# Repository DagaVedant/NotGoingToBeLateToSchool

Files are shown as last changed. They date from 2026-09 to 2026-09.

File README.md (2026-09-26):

# NotGoingToBeLateToSchool

a 9 key alarm clock that makes you type a code to shut it up.

built on a xiao esp32c3 for BLARE. during the day it sits on my desk cycling through
weather, hackatime hours, now playing and world clocks. at 6am it tells my phone to start
playing spotify instead of screaming at me with a piezo. you get 3 snoozes, and on the 3rd
one you have to type a code on the keypad before it stops.

every alarm clock i've had is useless for the 16 hours a day you're awake, and way too easy
to snooze into oblivion. this one tries to fix both.

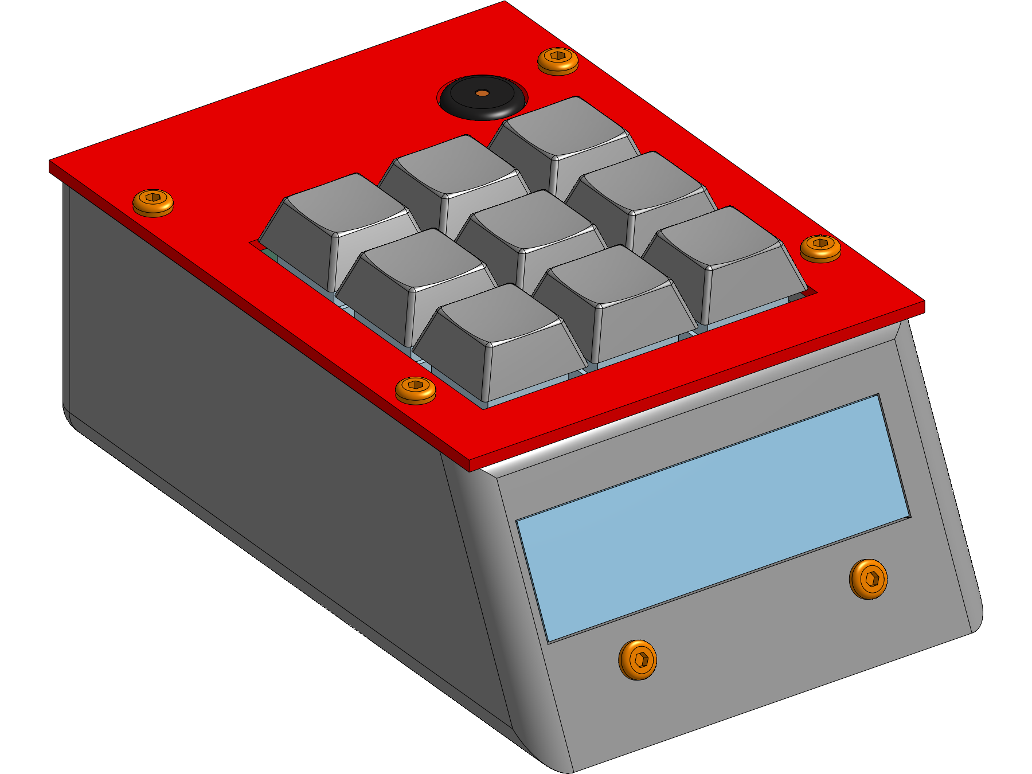
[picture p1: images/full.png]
notgoingtobelatetoschool


the top plate and the pcb share hardware: one m3x16 screw per corner runs down through the
top plate boss and the board into the same heatset insert the pcb post already carries, so
there's no separate top-plate insert or screw anymore. simpler, but the board can't come out
without pulling the top plate first. the bosses sit over the board, so they need a bit of
support when printing the base.

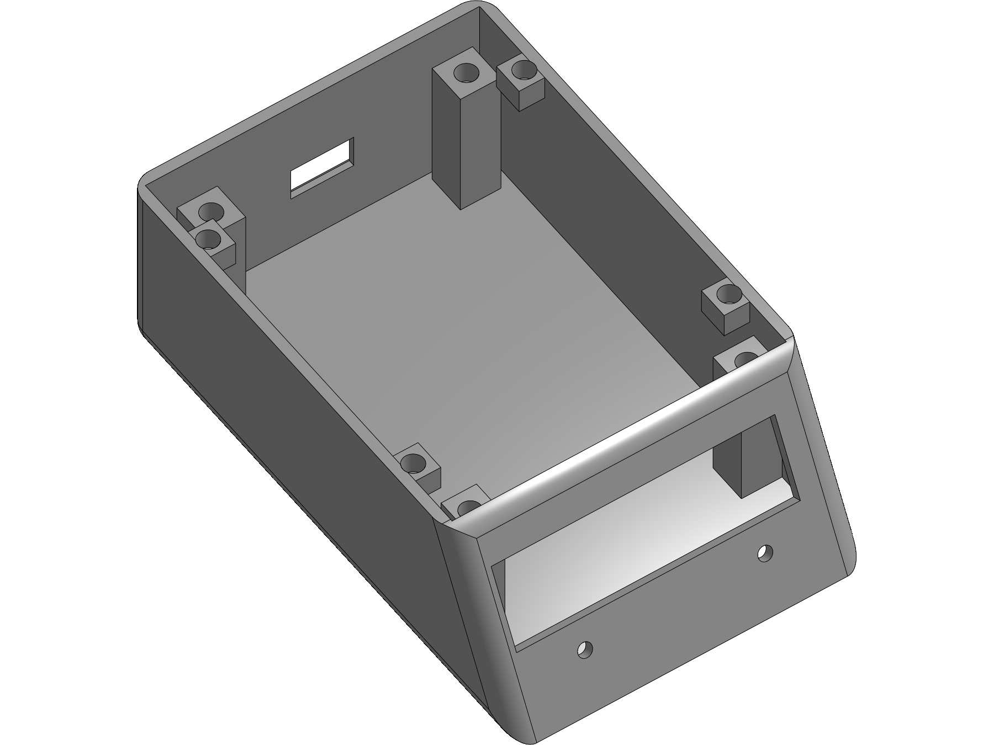
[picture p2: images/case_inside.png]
inside the case


the pcb sits on four posts that land exactly on its mounting holes. the xiao is socketed on
the underside, so its usb-c port ends up 13mm below the board, and the slot in the back wall
is cut around that spot, not at board height.

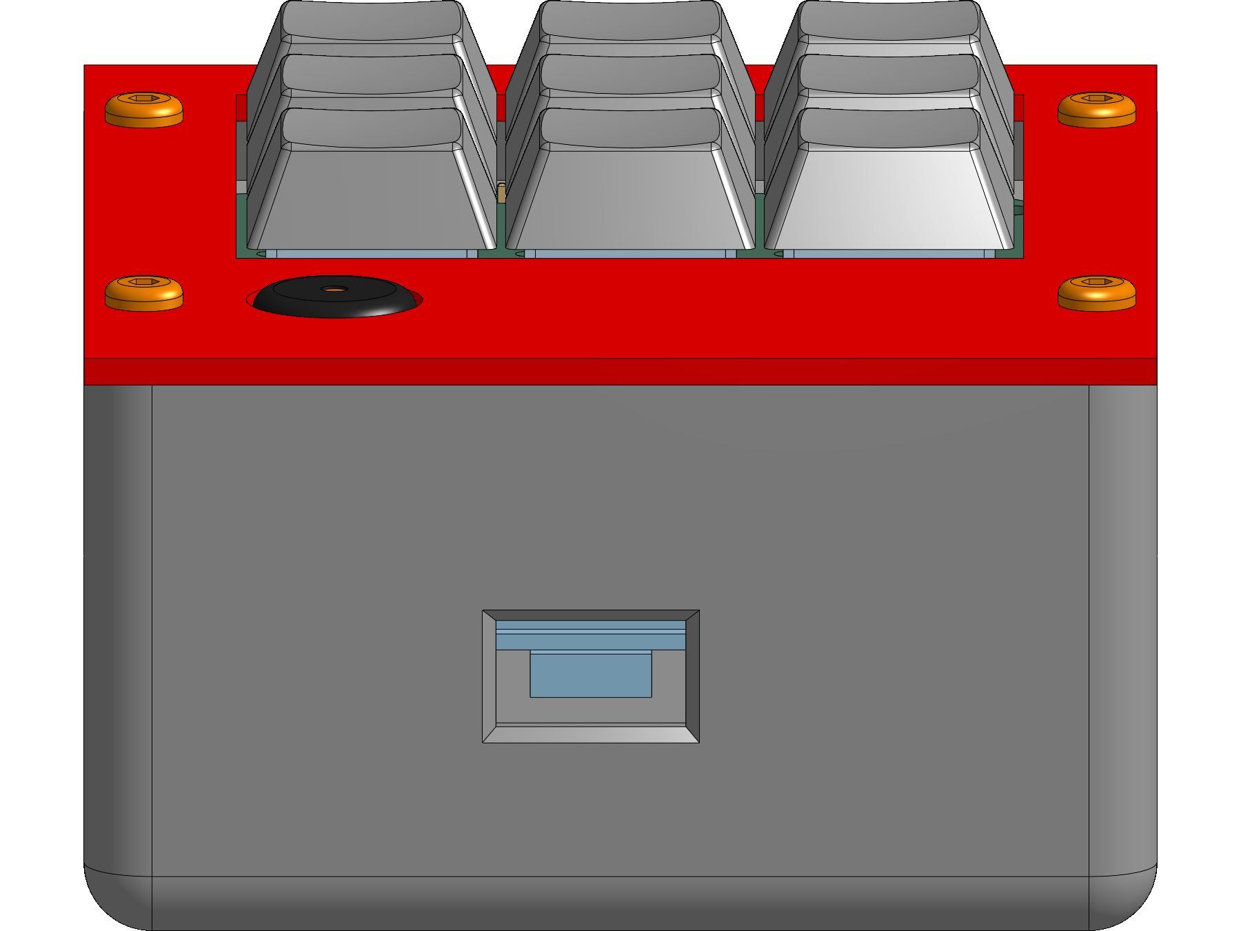
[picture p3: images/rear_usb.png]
rear usb slot


## what it does

**ambient**, all day

- auto rotates through weather / hackatime hours / now playing / world clocks
- spinning globe on the clock face, same animation as the oled on my hackpad
- one small json from a relay covers all four pages, so the clock makes one https request
  a minute instead of juggling four apis itself

**alarm**, at 6am

- multiple alarms, each with its own days of the week, all editable on the device
- 3 snoozes max. the first two are normal, on the 3rd it drops into code entry and keeps
  going until you type the right code
- screen fades up from near black to full brightness over the 15 min before the alarm
- escalating piezo buzzer that speeds up the longer you ignore it

**ble**, written and compiling, never run on hardware

- pairs as a ble media remote so the alarm hits play on my phone instead of buzzing
- iphone notifications over ancs

## the board

69.5 x 97mm, 2 layers, 25 footprints. 461 tracks, 14 vias, about 1.5m of copper. drc clean,
nothing unrouted.

- keys on the top side at 19.05 pitch so the caps clear each other
- xiao and display header on the underside, so the top face is just keycaps and the buzzer
- xiao at the back with usb-c out the rear, on 2.54 sockets so it can be pulled out
- 8 pin display header at the front edge so the jumper run to the screen is short
- one diode per switch, sitting in the 3.45mm gap directly below it
- 4x m3 mounting holes, pushed out to the corners so they clear the key block

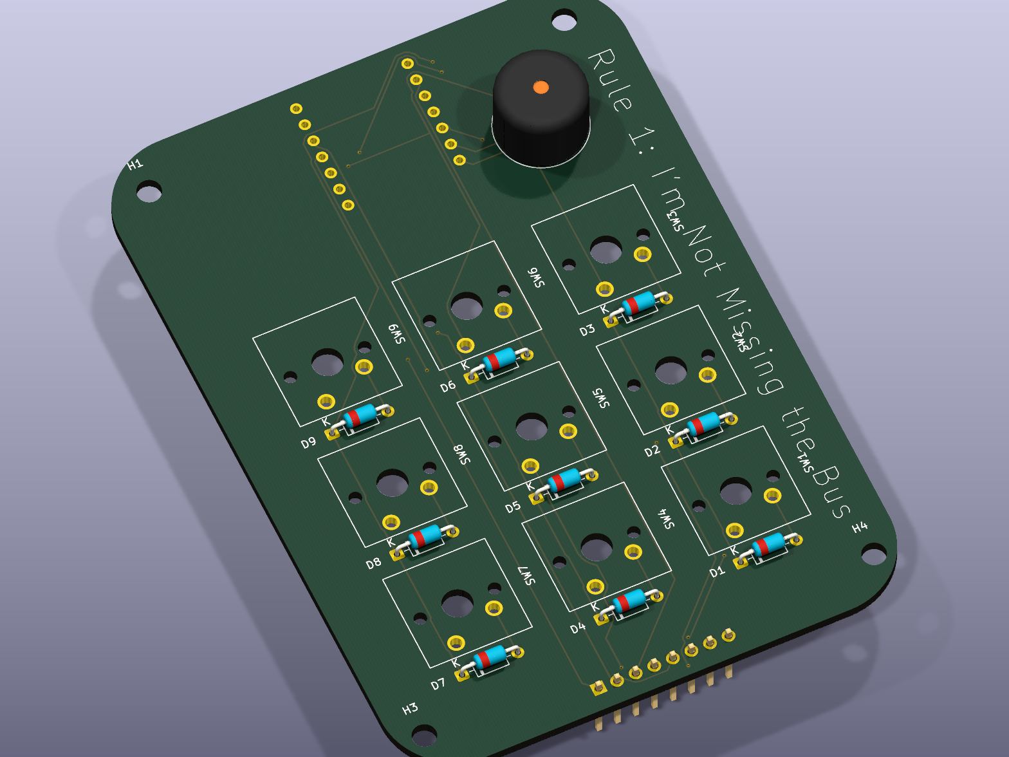
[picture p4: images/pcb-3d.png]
pcb


nine switches in a 3x3 matrix, one 1n4148 per key so holding two keys down cannot ghost a
third.

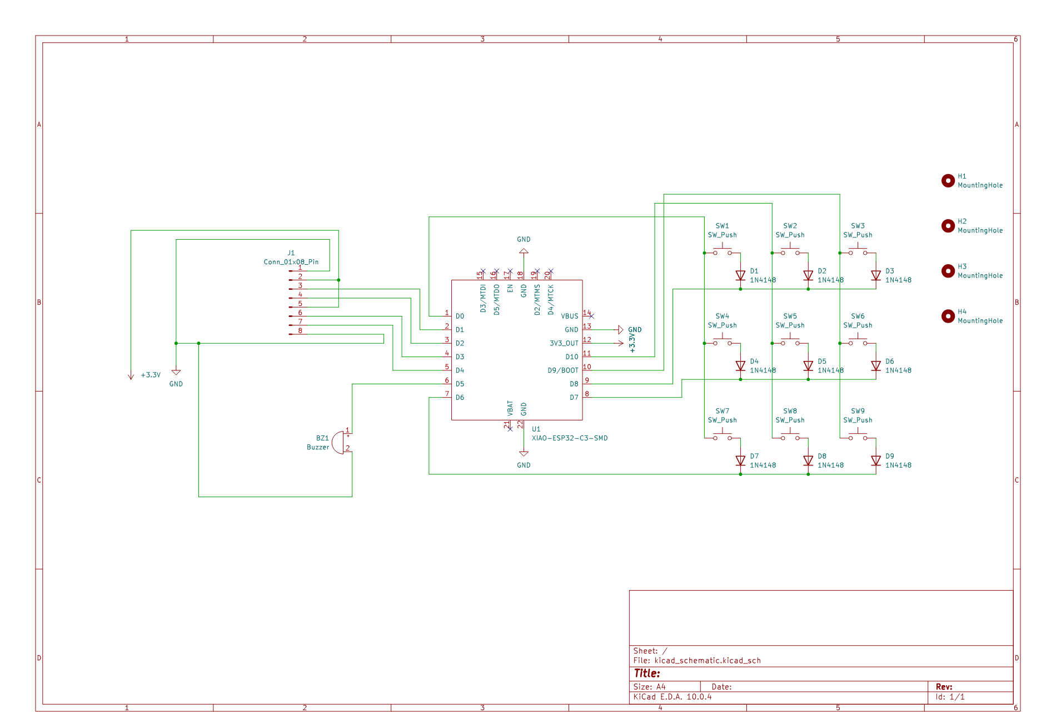
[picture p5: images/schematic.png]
schematic


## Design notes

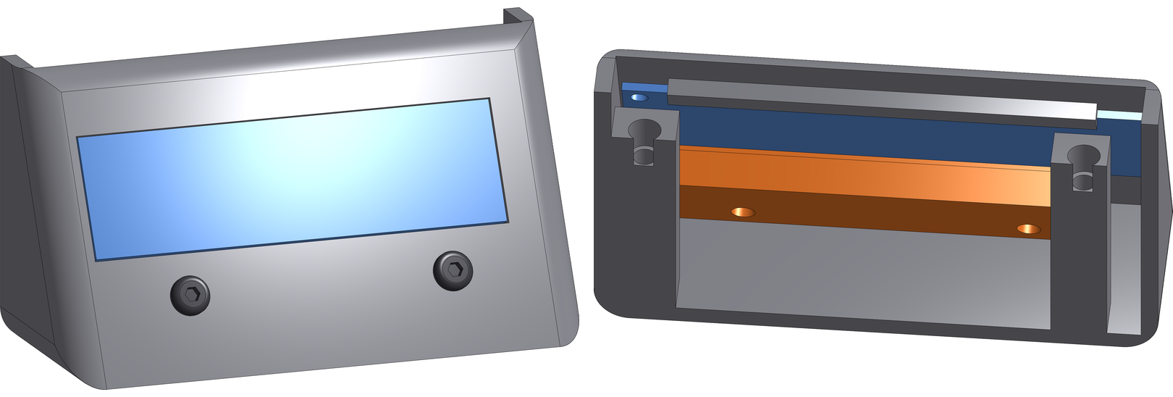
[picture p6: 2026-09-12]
images/display_mounting.png

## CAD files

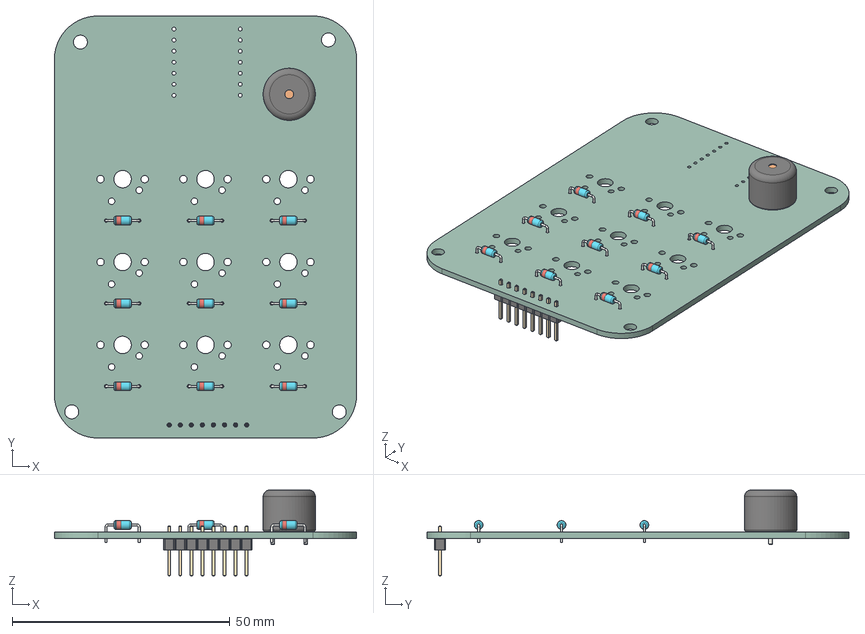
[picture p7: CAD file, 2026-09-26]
CAD/PCB assembly.step
69.5 x 97.0 x 19.8 mm
D_DO-35_SOD27_P7.62mm_Horizontal_4 x 2
D_DO-35_SOD27_P7.62mm_Horizontal_8 x 2
kicad_schematic_PCB
D_DO-35_SOD27_P7.62mm_Horizontal_5 x 2
PinHeader_1x08_P254mm_Vertical
D_DO-35_SOD27_P7.62mm_Horizontal_6 x 2
D_DO-35_SOD27_P7.62mm_Horizontal_1 x 2
D_DO-35_SOD27_P7.62mm_Horizontal_7 x 2
Buzzer_12x95RM76
D_DO-35_SOD27_P7.62mm_Horizontal x 2
D_DO-35_SOD27_P7.62mm_Horizontal_2 x 2
D_DO-35_SOD27_P7.62mm_Horizontal_3 x 2

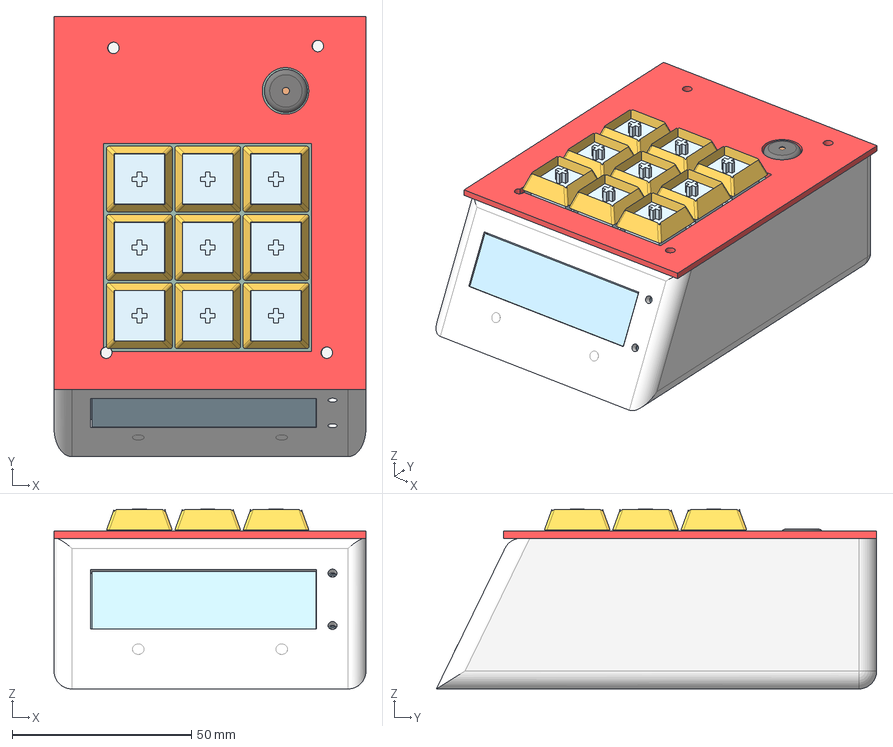
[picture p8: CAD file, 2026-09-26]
CAD/Full Assembly.step
87.0 x 122.8 x 50.2 mm
MX switch x 9
XIAO ESP32C3 on sockets
TFT display
D_DO-35_SOD27_P7.62mm_Horizontal_8 x 2
D_DO-35_SOD27_P7.62mm_Horizontal_4 x 2
D_DO-35_SOD27_P7.62mm_Horizontal_1 x 2
D_DO-35_SOD27_P7.62mm_Horizontal_7 x 2
PinHeader_1x08_P254mm_Vertical
D_DO-35_SOD27_P7.62mm_Horizontal_6 x 2
D_DO-35_SOD27_P7.62mm_Horizontal_5 x 2
Buzzer_12x95RM76
D_DO-35_SOD27_P7.62mm_Horizontal x 2
D_DO-35_SOD27_P7.62mm_Horizontal_3 x 2
D_DO-35_SOD27_P7.62mm_Horizontal_2 x 2
kicad_schematic_PCB

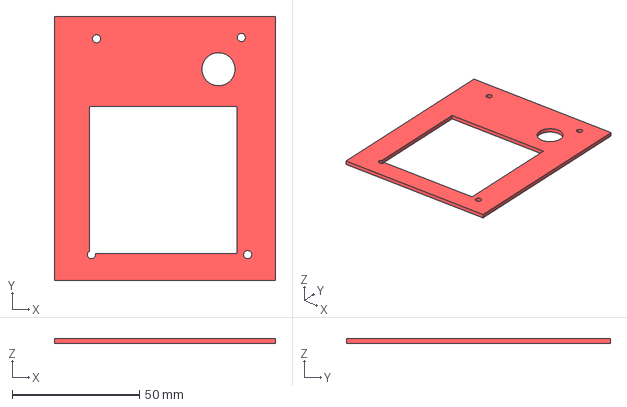
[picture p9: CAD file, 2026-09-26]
CAD/Top.step
87.0 x 104.0 x 2.00 mm

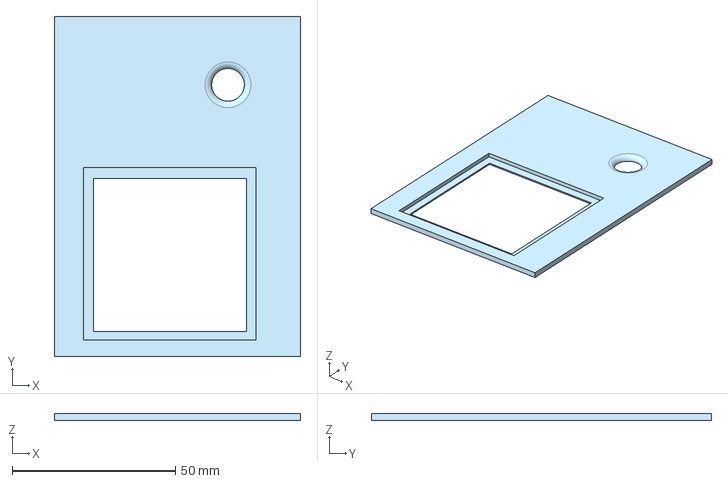
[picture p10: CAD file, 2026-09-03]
Top CAD.step
75.3 x 104.0 x 2.00 mm

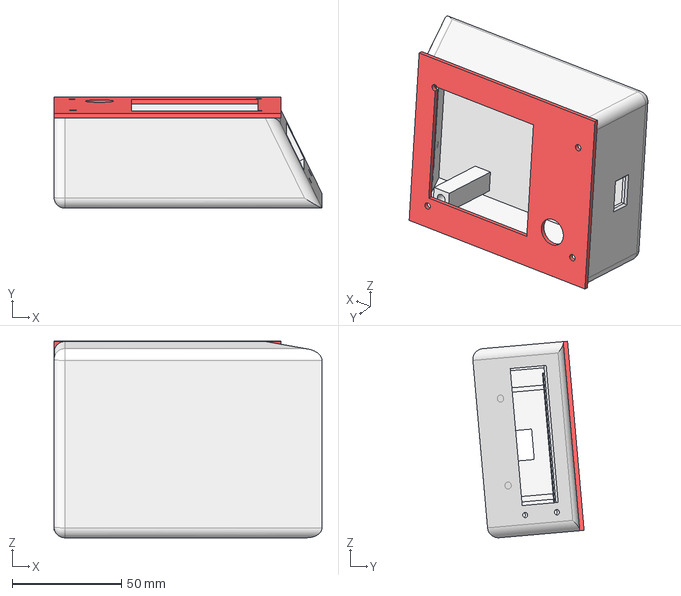
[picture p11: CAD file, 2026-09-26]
CAD/Top and Bottom.step
122.8 x 51.0 x 90.1 mm

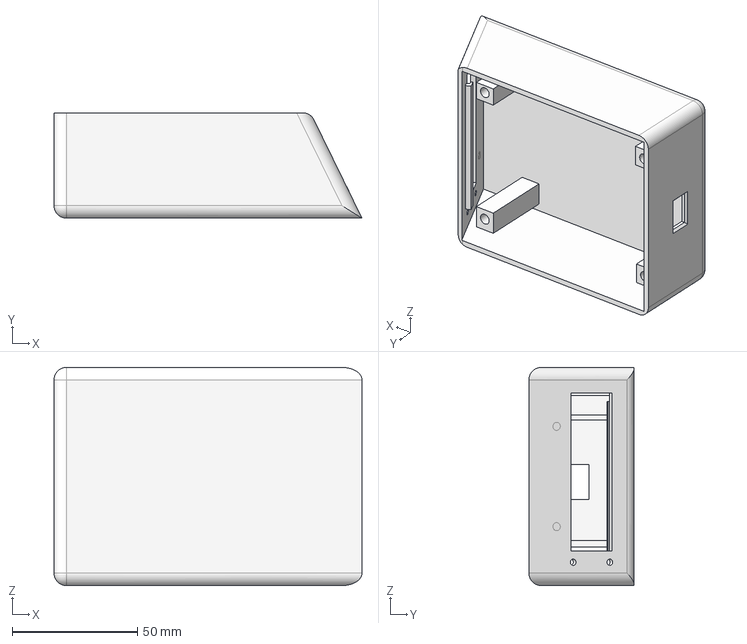
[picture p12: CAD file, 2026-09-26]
CAD/Bottom.step
122.8 x 42.0 x 87.0 mm

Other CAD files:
PCB/board.step

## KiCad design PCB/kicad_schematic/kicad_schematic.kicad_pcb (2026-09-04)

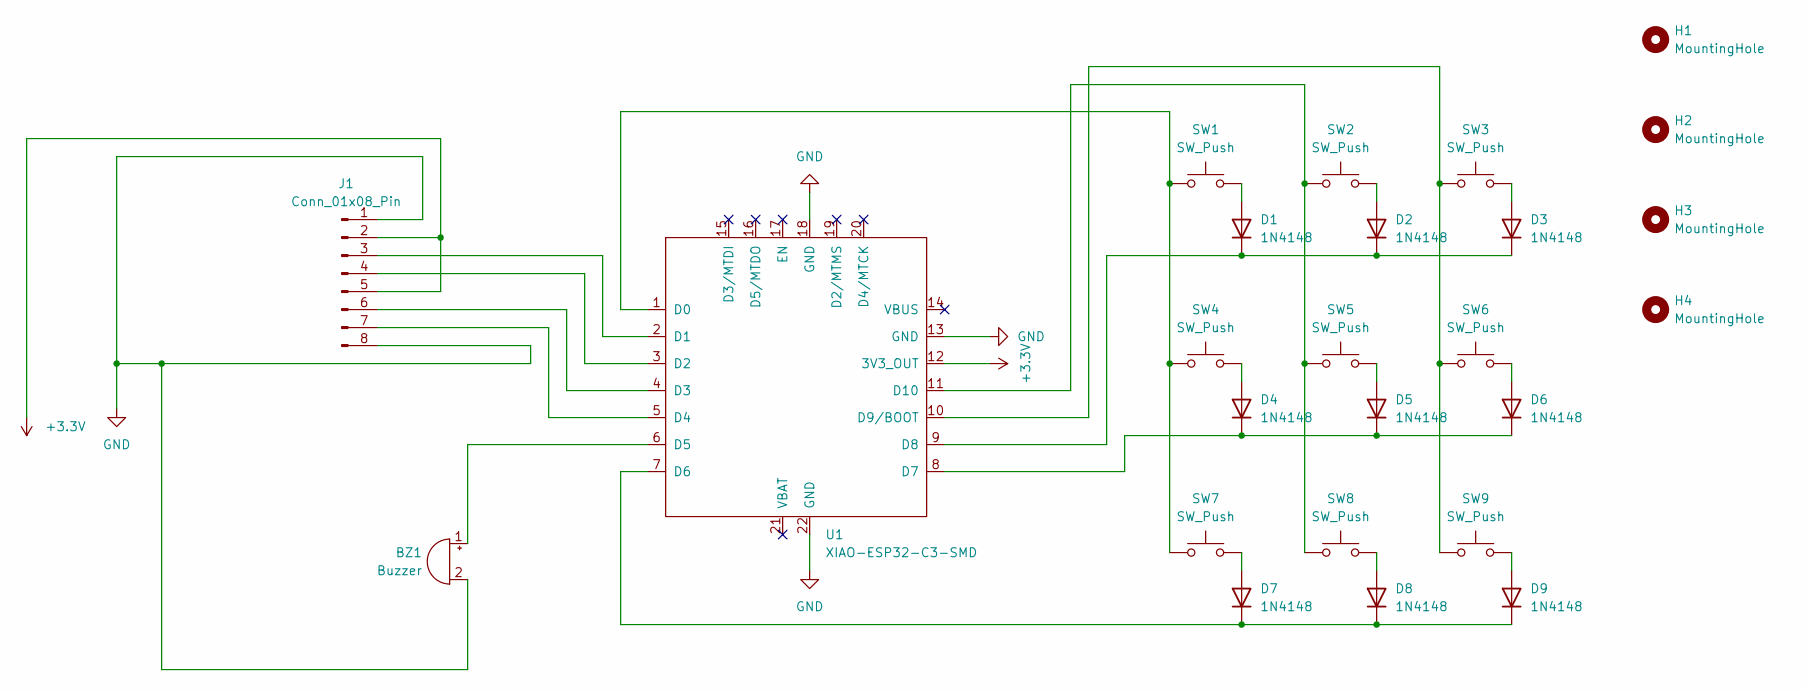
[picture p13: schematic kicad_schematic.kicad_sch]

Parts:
BZ1: Buzzer; Buzzer_12x9.5RM7.6
D1, D2, D3, D4, D5, D6, D7, D8, D9: 1N4148; D_DO-35_SOD27_P7.62mm_Horizontal
H1, H2, H3, H4: MountingHole; MountingHole_3.2mm_M3
J1: Conn_01x08_Pin; PinSocket_1x08_P2.54mm_Vertical
SW1, SW2, SW3, SW4, SW5, SW6, SW7, SW8, SW9: SW_Push; SW_Cherry_MX_1.00u_PCB
U1: XIAO-ESP32-C3-SMD; XIAO-ESP32-C3-DIP

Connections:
+3.3V: J1.2, J1.5, U1.12 (3V3_OUT)
GND: BZ1.2 (-), J1.1, J1.8, U1.13 (GND), U1.18 (GND), U1.22 (GND)
unnamed: BZ1.1 (+), U1.6 (D5)
unnamed: D1.2 (A), SW1.2
unnamed: D1.1 (K), D2.1 (K), D3.1 (K), U1.9 (D8)
unnamed: D2.2 (A), SW2.2
unnamed: D3.2 (A), SW3.2
unnamed: D4.2 (A), SW4.2
unnamed: D4.1 (K), D5.1 (K), D6.1 (K), U1.8 (D7)
unnamed: D5.2 (A), SW5.2
unnamed: D6.2 (A), SW6.2
unnamed: D7.2 (A), SW7.2
unnamed: D7.1 (K), D8.1 (K), D9.1 (K), U1.7 (D6)
unnamed: D8.2 (A), SW8.2
unnamed: D9.2 (A), SW9.2
unnamed: J1.3, U1.2 (D1)
unnamed: J1.4, U1.3 (D2)
unnamed: J1.6, U1.4 (D3)
unnamed: J1.7, U1.5 (D4)
unnamed: SW1.1, SW4.1, SW7.1, U1.1 (D0)
unnamed: SW3.1, SW6.1, SW9.1, U1.10 (D9/BOOT)
unnamed: SW2.1, SW5.1, SW8.1, U1.11 (D10)

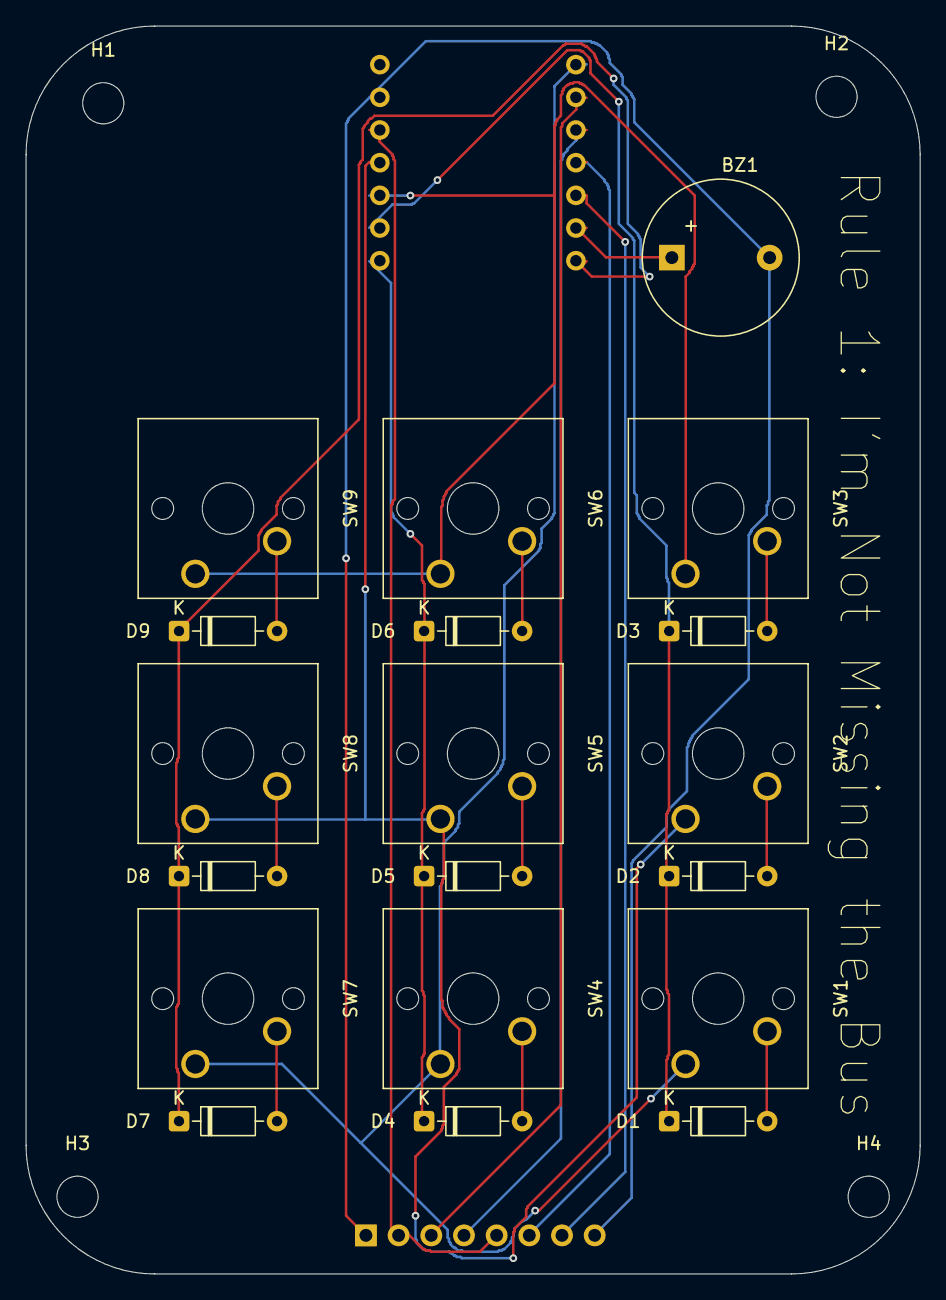
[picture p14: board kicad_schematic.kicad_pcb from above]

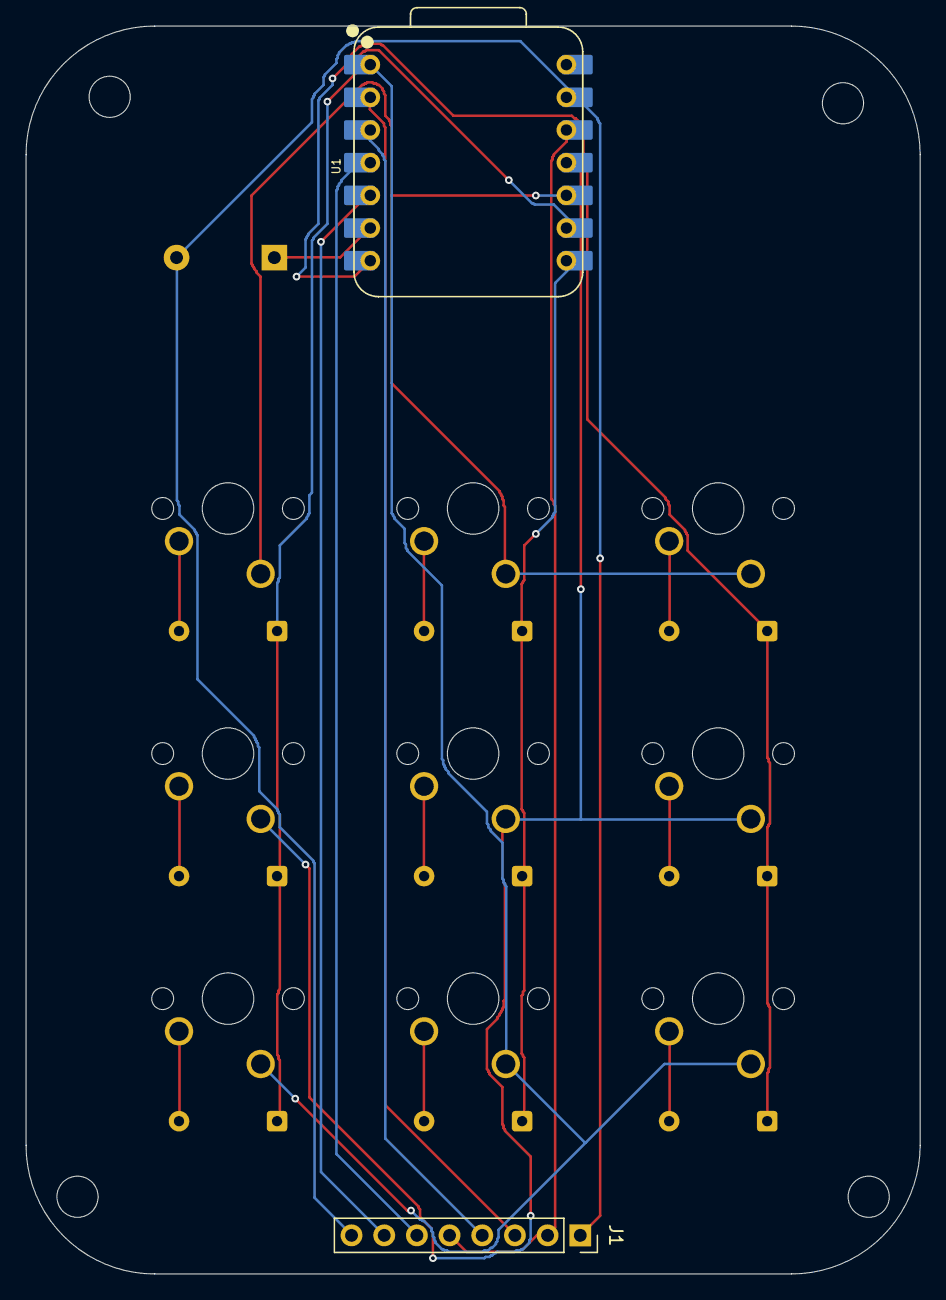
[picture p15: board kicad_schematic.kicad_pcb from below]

Board: 2 copper layers, 69.5 x 97.0 mm, 25 parts (2 on the bottom side), 22 nets.

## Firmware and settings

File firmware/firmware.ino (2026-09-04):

/*
  NotGoingToBeLateToSchool
  9 key alarm clock on a Seeed XIAO ESP32C3

  the display setup here comes from the blare firmware guide:
  https://blare.hackclub.com/docs/firmware
  the spinning globe is the same animation as the oled on my hackpad.

  what works:
    - wifi + ntp so it knows the time
    - clock face with the spinning globe
    - 3x3 key matrix
    - 4 alarms, each with its own days of the week, all editable on the device
    - rings with an escalating buzzer
    - screen fades up starting 15 min before an alarm
    - 3 snoozes max, then you have to type the code
    - info pages: weather, hackatime, now playing, world clocks
    - all four pages come from one json off the relay, one request a minute
    - pages auto rotate, or arrow through them yourself

  ble is on. it compiles clean against NimBLE-Arduino 2.5.1 but has never run
  on hardware, because the board does not exist yet. build it on the Minimal
  SPIFFS partition, see the flash numbers below.

  board: esp32 core 3.3.11, Seeed XIAO ESP32C3
  libraries: Adafruit GFX, Adafruit ST7735/ST7789, Adafruit BusIO,
             ArduinoJson 7, and NimBLE-Arduino only if ENABLE_BLE is 1

  flash, measured:
    ENABLE_BLE 0  ->  1155141 bytes, 88% of the default partition. fits.
    ENABLE_BLE 1  ->  1394487 bytes, 106% of the default partition, so the
                      default does NOT fit. on Minimal SPIFFS it is 70% and
                      still has ota, which is what this is set up for.
                      Huge APP also works, 44%, but drops ota.
*/

#include <Adafruit_GFX.h>
#include <Adafruit_ST7789.h>
#include <SPI.h>
#include <WiFi.h>
#include <HTTPClient.h>
#include <WiFiClientSecure.h>
#include <ArduinoJson.h>
#include <time.h>
#include <Preferences.h>
#include "secrets.h"
#include "globe.h"

// BUILD NOTE: with this at 1 the sketch is 1394487 bytes, which overflows the
// default partition. set Tools > Partition Scheme to "Minimal SPIFFS (1.9MB
// APP with OTA/128KB SPIFFS)" or it will not fit.
#define ENABLE_BLE 1    // 1 = build the spotify remote and iphone notifications

// these have to be up here with the other includes. the .ino preprocessor
// hoists its generated prototypes to the top of the file, so if the nimble
// headers come later the prototypes are written before the types exist.
#if ENABLE_BLE
#include <NimBLEDevice.h>
#include <NimBLEHIDDevice.h>
#endif

// ---------- pins ----------
// see the readme for the full pin map

#define TFT_SCLK 3   // D1, labeled SCL on the screen
#define TFT_MOSI 4   // D2, labeled SDA on the screen
#define TFT_DC   5   // D3
#define TFT_CS   6   // D4
#define TFT_RST  -1  // tied to 3v3 on the board, so -1 = not connected
// BL is tied to gnd, so the backlight is just always on
#define BUZZER 7     // D5

// these have to match the board. rows are D0 D10 D9, columns are D6 D7 D8.
int rowPins[3] = {2, 10, 9};     // top to bottom
int colPins[3] = {21, 20, 8};    // left to right

// key numbering, 0 to 8, left to right then top to bottom:
//   0 HOME   1 UP     2 BACK
//   3 LEFT   4 OK     5 RIGHT
//   6 ALARM  7 DOWN   8 SNOOZE
// in code entry the same keys are digits 1 to 9

#define KEY_HOME 0
#define KEY_UP 1
#define KEY_BACK 2
#define KEY_LEFT 3
#define KEY_OK 4
#define KEY_RIGHT 5
#define KEY_ALARM 6
#define KEY_DOWN 7
#define KEY_SNOOZE 8

// ---------- display ----------
// the plain Adafruit_ST7789 class hides setOffsets(), so this subclass
// exposes it. straight out of the blare guide.

class MyST7789 : public Adafruit_ST7789 {
public:
  MyST7789(int8_t cs, int8_t dc, int8_t mosi, int8_t sclk, int8_t rst)
    : Adafruit_ST7789(cs, dc, mosi, sclk, rst) {}
  void setOffsets(uint8_t col, uint8_t row) {
    _colstart = _colstart2 = col;
    _rowstart = _rowstart2 = row;
  }
};

MyST7789 tft(TFT_CS, TFT_DC, TFT_MOSI, TFT_SCLK, TFT_RST);

// where the globe sits on the clock face
#define GLOBE_X 8
#define GLOBE_Y 22

// ---------- modes ----------

#define MODE_CLOCK 0
#define MODE_RING 1
#define MODE_SNOOZE 2
#define MODE_CODE 3
#define MODE_LIST 4      // list of the 4 alarms
#define MODE_EDIT 5      // editing one alarm

int mode = MODE_CLOCK;

// ---------- alarms ----------
// days is a bit per weekday, bit 0 = sunday, same order as tm_wday.
// days == 0 means every day.

struct Alarm {
  uint8_t hour;
  uint8_t minute;
  uint8_t days;
  uint8_t on;
};

#define NALARMS 4
Alarm alarms[NALARMS];

int listSel = 0;     // which alarm the list is pointing at
int editSel = 0;     // which alarm we are editing
int editField = 0;   // 0 hour, 1 minute, 2 days, 3 on/off
int daySel = 0;      // which day the days field is pointing at
int ringingAlarm = -1;

const char *dayLetters[7] = {"S", "M", "T", "W", "T", "F", "S"};

Preferences prefs;

// ---------- snooze and code ----------

int snoozeCount = 0;
unsigned long snoozeUntil = 0;
int snoozeMinutes = 9;

int code[4] = {1, 2, 3, 4};
int typed[4];
int typedCount = 0;

// ---------- keys ----------

bool keyDown[9];
bool keyWas[9];
int justPressed = -1;

// ---------- timers ----------

unsigned long lastScan = 0;
unsigned long lastBeep = 0;
unsigned long lastGlobe = 0;
unsigned long lastFetch = 0;
unsigned long lastPageFlip = 0;
unsigned long lastKeyAt = 0;
unsigned long ringStarted = 0;
bool beepOn = false;

int globeFrame = 0;
int lastMinShown = -1;
int lastAwayShown = -999;

// ---------- info pages ----------
// 0 is the clock, the rest come off the relay

#define PAGE_CLOCK 0
#define PAGE_WEATHER 1
#define PAGE_HACKATIME 2
#define PAGE_PLAYING 3
#define PAGE_WORLD 4
#define NPAGES 5

int page = PAGE_CLOCK;
bool pageDirty = true;

// what the relay gave us last time
struct Info {
  bool ok;
  int   temp;
  int   hi;
  int   lo;
  char  sky[24];
  int   todayMin;
  int   weekMin;
  bool  playing;
  char  title[40];
  char  artist[40];
  char  cityName[3][10];
  int   cityOffset[3];   // minutes from utc
  int   cityCount;
  char  note[64];        // last notification, from ble
  bool  noteFresh;
};

Info info;

// ---------- forward declarations ----------

void showMessage(const char *msg);
void startWifi();
void loadAlarms();
void saveAlarms();
void drawList();
void drawEdit();
void drawRinging();
void drawCodeEntry();
bool bleConnected();
void blePlay();
void bleHookAncs();
#if ENABLE_BLE
void bleStart();
#endif

// ---------- setup ----------

void setup() {
  Serial.begin(115200);

  for (int i = 0; i < 3; i++) {
    pinMode(rowPins[i], INPUT_PULLUP);
    pinMode(colPins[i], OUTPUT);
    digitalWrite(colPins[i], HIGH);
  }
  pinMode(BUZZER, OUTPUT);
  digitalWrite(BUZZER, LOW);

  tft.init(76, 284);          // our panel size, portrait
  tft.setOffsets(82, 18);     // offsets for the weird resolution
  tft.invertDisplay(false);
  tft.setRotation(1);         // landscape, use 3 if it comes out upside down
  tft.fillScreen(ST77XX_BLACK);

  memset(&info, 0, sizeof(info));
  loadAlarms();

  showMessage("connecting");
  startWifi();

#if ENABLE_BLE
  bleStart();
#endif

  pageDirty = true;
}

// ---------- saving ----------
// the four alarms go into one blob so it is a single read and write

void loadAlarms() {
  prefs.begin("clock", false);
  size_t got = prefs.getBytes("alarms", alarms, sizeof(alarms));
  if (got != sizeof(alarms)) {
    for (int i = 0; i < NALARMS; i++) {
      alarms[i].hour = 7;
      alarms[i].minute = 0;
      alarms[i].days = 0;
      alarms[i].on = 0;
    }
    alarms[0].hour = 6;
    alarms[0].minute = 30;
    alarms[0].days = 0b0111110;   // mon to fri
  }
  for (int i = 0; i < 4; i++) {
    char k[4] = {'c', (char)('0' + i), 0, 0};
    code[i] = prefs.getInt(k, code[i]);
  }
}

void saveAlarms() {
  prefs.putBytes("alarms", alarms, sizeof(alarms));
}

// ---------- wifi ----------

void startWifi() {
  WiFi.begin(WIFI_SSID, WIFI_PASS);
  unsigned long start = millis();
  while (WiFi.status() != WL_CONNECTED && millis() - start < 15000) {
    delay(250);
  }

  if (WiFi.status() == WL_CONNECTED) {
    configTime(0, 0, "pool.ntp.org");
    setenv("TZ", TZ_STRING, 1);
    tzset();
    showMessage("syncing");
  } else {
    showMessage("no wifi");
  }
}

// ---------- key matrix ----------
// drive one column low at a time and read the three rows.
// a pressed key pulls its row low through its diode.

void scanKeys() {
  justPressed = -1;

  for (int c = 0; c < 3; c++) {
    digitalWrite(colPins[c], LOW);
    delayMicroseconds(50);

    for (int r = 0; r < 3; r++) {
      int key = r * 3 + c;
      keyDown[key] = (digitalRead(rowPins[r]) == LOW);
    }

    digitalWrite(colPins[c], HIGH);
  }

  for (int k = 0; k < 9; k++) {
    if (keyDown[k] && !keyWas[k]) {
      justPressed = k;
      lastKeyAt = millis();
    }
    keyWas[k] = keyDown[k];
  }
}

// ---------- time helpers ----------

bool getNow(int &h, int &m, int &s, int &wday) {
  struct tm t;
  if (!getLocalTime(&t, 100)) return false;
  h = t.tm_hour;
  m = t.tm_min;
  s = t.tm_sec;
  wday = t.tm_wday;
  return true;
}

bool alarmRunsToday(const Alarm &a, int wday) {
  if (!a.on) return false;
  if (a.days == 0) return true;             // 0 means every day
  return (a.days >> wday) & 1;
}

// minutes until the soonest armed alarm, or -1 if none.
// only looks at today and tomorrow, which is all the sunrise ramp needs.
int minutesToAlarm(int h, int m, int wday) {
  int now = h * 60 + m;
  int best = -1;

  for (int d = 0; d < 2; d++) {
    int day = (wday + d) % 7;
    for (int i = 0; i < NALARMS; i++) {
      if (!alarmRunsToday(alarms[i], day)) continue;
      int t = alarms[i].hour * 60 + alarms[i].minute + d * 1440;
      int diff = t - now;
      if (diff < 0) continue;
      if (best < 0 || diff < best) best = diff;
    }
  }
  return best;
}

// which alarm should be going off right now, or -1
int alarmDueNow(int h, int m, int s, int wday) {
  if (s >= 2) return -1;
  for (int i = 0; i < NALARMS; i++) {
    if (!alarmRunsToday(alarms[i], wday)) continue;
    if (alarms[i].hour == h && alarms[i].minute == m) return i;
  }
  return -1;
}

// ---------- the relay ----------
// one https get a minute, one json back, everything on it. building four
// api calls into the clock would not fit in flash and would need four sets
// of keys on the device, so the relay does it and hands over the answer.
//
// what it has to send back:
// {
//   "weather":   {"temp":12,"hi":15,"lo":8,"sky":"light rain"},
//   "hackatime": {"today":143,"week":812},
//   "playing":   {"is":true,"title":"...","artist":"..."},
//   "clocks":    [{"name":"UTC","offset":0},{"name":"SF","offset":-480}]
// }
// temps in celsius, hackatime in minutes, clock offsets in minutes from utc.

void fetchInfo() {
  if (WiFi.status() != WL_CONNECTED) { info.ok = false; return; }

  WiFiClientSecure net;
  net.setInsecure();          // the relay is mine and it is read only
  HTTPClient http;
  http.setTimeout(6000);
  if (!http.begin(net, RELAY_URL)) { info.ok = false; return; }

  int codeHttp = http.GET();
  if (codeHttp != 200) { http.end(); info.ok = false; return; }

  JsonDocument doc;
  DeserializationError err = deserializeJson(doc, http.getStream());
  http.end();
  if (err) { info.ok = false; return; }

  info.temp = doc["weather"]["temp"] | 0;
  info.hi   = doc["weather"]["hi"] | 0;
  info.lo   = doc["weather"]["lo"] | 0;
  strlcpy(info.sky, doc["weather"]["sky"] | "", sizeof(info.sky));

  info.todayMin = doc["hackatime"]["today"] | 0;
  info.weekMin  = doc["hackatime"]["week"] | 0;

  info.playing = doc["playing"]["is"] | false;
  strlcpy(info.title,  doc["playing"]["title"] | "", sizeof(info.title));
  strlcpy(info.artist, doc["playing"]["artist"] | "", sizeof(info.artist));

  info.cityCount = 0;
  for (JsonObject c : doc["clocks"].as<JsonArray>()) {
    if (info.cityCount >= 3) break;
    strlcpy(info.cityName[info.cityCount], c["name"] | "", 10);
    info.cityOffset[info.cityCount] = c["offset"] | 0;
    info.cityCount++;
  }

  info.ok = true;
}

// ---------- drawing ----------

void showMessage(const char *msg) {
  tft.fillScreen(ST77XX_BLACK);
  tft.setTextColor(ST77XX_WHITE);
  tft.setTextSize(3);
  tft.setCursor(0, 20);
  tft.print(msg);
}

// the sunrise ramp. the backlight is hardwired on, so instead of pwm
// we just draw in a brighter grey as the alarm gets closer.
uint16_t clockColour(int minsAway) {
  int level = 60;                       // normal brightness
  if (minsAway >= 0 && minsAway <= 15) {
    level = 60 + (15 - minsAway) * 13;  // fades up to about 255
    if (level > 255) level = 255;
  }
  return tft.color565(level, level, level);
}

void print2(int v) {
  if (v < 10) tft.print("0");
  tft.print(v);
}

// header used by all the info pages
void pageHeader(const char *name) {
  tft.fillScreen(ST77XX_BLACK);
  tft.setTextSize(1);
  tft.setTextColor(tft.color565(90, 90, 90));
  tft.setCursor(6, 6);
  tft.print(name);
}

// only the globe moves most of the time, so it gets redrawn on its own
void drawGlobe(uint16_t colour) {
  tft.drawBitmap(GLOBE_X, GLOBE_Y, globe[globeFrame],
                 GLOBE_SIZE, GLOBE_SIZE, colour, ST77XX_BLACK);
}

void drawClockFace(bool full) {
  int h, m, s, wday;
  if (!getNow(h, m, s, wday)) {
    showMessage("syncing");
    return;
  }

  int away = minutesToAlarm(h, m, wday);
  uint16_t col = clockColour(away);

  // the whole face only gets repainted when the minute or the ramp changes
  if (full || m != lastMinShown || away != lastAwayShown) {
    lastMinShown = m;
    lastAwayShown = away;

    tft.fillScreen(ST77XX_BLACK);
    tft.setTextColor(col);
    tft.setTextSize(6);
    tft.setCursor(50, 14);
    print2(h);
    tft.print(":");
    print2(m);

    tft.setTextSize(1);
    tft.setTextColor(ST77XX_WHITE);

    int next = -1;
    for (int i = 0; i < NALARMS; i++) if (alarms[i].on) { next = i; break; }
    tft.setCursor(238, 20);
    if (next >= 0 && away >= 0) {
      print2(away / 60);
      tft.print("h");
      print2(away % 60);
      tft.setCursor(238, 34);
      tft.print("to go");
    } else {
      tft.print("no alarm");
    }

    if (info.noteFresh) {
      tft.setTextColor(tft.color565(255, 190, 60));
      tft.setCursor(50, 62);
      tft.print(info.note);
    }
  }

  drawGlobe(col);
}

void drawWeather() {
  pageHeader("weather");
  tft.setTextColor(ST77XX_WHITE);
  if (!info.ok) { tft.setTextSize(2); tft.setCursor(6, 32); tft.print("no data"); return; }

  tft.setTextSize(5);
  tft.setCursor(6, 22);
  tft.print(info.temp);
  tft.print("C");

  tft.setTextSize(1);
  tft.setCursor(150, 26);
  tft.print(info.sky);
  tft.setCursor(150, 42);
  tft.print("hi ");
  tft.print(info.hi);
  tft.print("  lo ");
  tft.print(info.lo);
}

void drawHackatime() {
  pageHeader("hackatime");
  tft.setTextColor(ST77XX_WHITE);
  if (!info.ok) { tft.setTextSize(2); tft.setCursor(6, 32); tft.print("no data"); return; }

  tft.setTextSize(5);
  tft.setCursor(6, 22);
  tft.print(info.todayMin / 60);
  tft.print("h");
  print2(info.todayMin % 60);

  tft.setTextSize(1);
  tft.setCursor(180, 26);
  tft.print("today");
  tft.setCursor(180, 42);
  tft.print("week ");
  tft.print(info.weekMin / 60);
  tft.print("h");
}

void drawPlaying() {
  pageHeader("now playing");
  tft.setTextColor(ST77XX_WHITE);
  if (!info.ok || !info.playing) {
    tft.setTextSize(2);
    tft.setCursor(6, 32);
    tft.print("nothing playing");
    return;
  }
  tft.setTextSize(2);
  tft.setCursor(6, 24);
  tft.print(info.title);
  tft.setTextSize(1);
  tft.setTextColor(tft.color565(140, 140, 140));
  tft.setCursor(6, 48);
  tft.print(info.artist);
}

void drawWorld() {
  pageHeader("world");
  tft.setTextColor(ST77XX_WHITE);

  time_t raw = time(nullptr);
  struct tm utc;
  gmtime_r(&raw, &utc);
  int utcMin = utc.tm_hour * 60 + utc.tm_min;

  if (!info.ok || info.cityCount == 0) {
    tft.setTextSize(2); tft.setCursor(6, 32); tft.print("no data"); return;
  }

  int x = 6;
  for (int i = 0; i < info.cityCount; i++) {
    int t = ((utcMin + info.cityOffset[i]) % 1440 + 1440) % 1440;
    tft.setTextSize(1);
    tft.setTextColor(tft.color565(140, 140, 140));
    tft.setCursor(x, 22);
    tft.print(info.cityName[i]);
    tft.setTextSize(3);
    tft.setTextColor(ST77XX_WHITE);
    tft.setCursor(x, 38);
    print2(t / 60);
    tft.print(":");
    print2(t % 60);
    x += 95;
  }
}

void drawRinging() {
  tft.fillScreen(ST77XX_BLACK);
  tft.setTextColor(ST77XX_WHITE);
  tft.setTextSize(4);
  tft.setCursor(4, 6);
  tft.print("WAKE UP");
  tft.setTextSize(1);
  tft.setCursor(4, 50);
  if (snoozeCount < 2) {
    tft.print("OK = stop   SNOOZE = ");
    tft.print(snoozeMinutes);
    tft.print(" more min");
  } else {
    tft.print("OK = stop   no snoozes left");
  }
#if ENABLE_BLE
  tft.setCursor(4, 62);
  tft.print(bleConnected() ? "phone is playing" : "phone not connected");
#endif
}

void drawCodeEntry() {
  tft.fillScreen(ST77XX_BLACK);
  tft.setTextColor(ST77XX_WHITE);
  tft.setTextSize(2);
  tft.setCursor(4, 6);
  tft.print("type the code");
  tft.setTextSize(4);
  tft.setCursor(4, 34);
  for (int i = 0; i < 4; i++) {
    if (i < typedCount) tft.print("*");
    else tft.print("_");
    tft.print(" ");
  }
}
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
void loop() {
  if (millis() - lastScan > 20) {
    lastScan = millis();
    scanKeys();
  }

  int h, m, s, wday;
  bool haveTime = getNow(h, m, s, wday);

  // pull the relay once a minute, but never while the alarm is going
  if (mode == MODE_CLOCK && millis() - lastFetch > 60000UL) {
    lastFetch = millis();
    fetchInfo();
    if (page != PAGE_CLOCK) pageDirty = true;
  }

  // has an alarm come due
  if (mode == MODE_CLOCK && haveTime) {
    int due = alarmDueNow(h, m, s, wday);
    if (due >= 0) startRinging(due);
  }

  // snooze finished
  if (mode == MODE_SNOOZE && millis() > snoozeUntil) {
    mode = MODE_RING;
    ringStarted = millis();
    blePlay();
    drawRinging();
  }

  if (mode == MODE_RING) {
    updateBuzzer(millis() - ringStarted);

    if (justPressed == KEY_OK) {
      stopRinging();
    }
    else if (justPressed == KEY_SNOOZE) {
      if (snoozeCount < 2) {
        snoozeCount++;
        stopBuzzer();
        snoozeUntil = millis() + (unsigned long)snoozeMinutes * 60000UL;
        mode = MODE_SNOOZE;
        showMessage("snoozed");
      } else {
        // third snooze, you have to type the code now
        typedCount = 0;
        mode = MODE_CODE;
        drawCodeEntry();
      }
    }
  }

  else if (mode == MODE_CODE) {
    updateBuzzer(millis() - ringStarted);

    if (justPressed >= 0) {
      typed[typedCount] = justPressed + 1;   // key 0 is digit 1
      typedCount++;
      drawCodeEntry();

      if (typedCount == 4) {
        bool ok = true;
        for (int i = 0; i < 4; i++) {
          if (typed[i] != code[i]) ok = false;
        }
        if (ok) {
          stopRinging();
        } else {
          typedCount = 0;
          showMessage("wrong");
          delay(600);
          drawCodeEntry();
        }
      }
    }
  }

  else if (mode == MODE_LIST) {
    if (justPressed == KEY_DOWN) { listSel = (listSel + 1) % NALARMS; drawList(); }
    if (justPressed == KEY_UP)   { listSel = (listSel + NALARMS - 1) % NALARMS; drawList(); }
    if (justPressed == KEY_ALARM) { alarms[listSel].on = !alarms[listSel].on; saveAlarms(); drawList(); }
    if (justPressed == KEY_OK)   { editSel = listSel; editField = 0; mode = MODE_EDIT; drawEdit(); }
    if (justPressed == KEY_BACK || justPressed == KEY_HOME) {
      saveAlarms();
      mode = MODE_CLOCK;
      page = PAGE_CLOCK;
      lastMinShown = -1;
      pageDirty = true;
    }
  }

  else if (mode == MODE_EDIT) {
    Alarm &a = alarms[editSel];
    bool touched = false;

    if (justPressed == KEY_RIGHT) { editField = (editField + 1) % 4; touched = true; }
    if (justPressed == KEY_LEFT)  { editField = (editField + 3) % 4; touched = true; }

    if (justPressed == KEY_UP || justPressed == KEY_DOWN) {
      int step = (justPressed == KEY_UP) ? 1 : -1;
      if (editField == 0) a.hour = (a.hour + 24 + step) % 24;
      if (editField == 1) a.minute = (a.minute + 60 + step * 5) % 60;
      if (editField == 2) daySel = (daySel + 7 + step) % 7;
      if (editField == 3) a.on = !a.on;
      touched = true;
    }

    // on the days field ALARM flips the day the cursor is under
    if (editField == 2 && justPressed == KEY_ALARM) {
      a.days ^= (1 << daySel);
      touched = true;
    }

    if (justPressed == KEY_OK) {
      saveAlarms();
      mode = MODE_LIST;
      drawList();
    } else if (touched) {
      drawEdit();
    }
  }

  else {   // MODE_CLOCK or MODE_SNOOZE, showing a page
    if (justPressed == KEY_ALARM) {
      listSel = 0;
      mode = MODE_LIST;
      drawList();
    }
    else if (justPressed == KEY_RIGHT) { page = (page + 1) % NPAGES; pageDirty = true; }
    else if (justPressed == KEY_LEFT)  { page = (page + NPAGES - 1) % NPAGES; pageDirty = true; }
    else if (justPressed == KEY_HOME)  { page = PAGE_CLOCK; pageDirty = true; info.noteFresh = false; }

    // auto rotate, but hold still for 20s after you touch a key
    if (millis() - lastKeyAt > 20000UL && millis() - lastPageFlip > 8000UL) {
      lastPageFlip = millis();
      page = (page + 1) % NPAGES;
      pageDirty = true;
    }

    if (page == PAGE_CLOCK) {
      // the globe keeps turning, the rest only repaints when it changes
      if (millis() - lastGlobe > 80) {
        lastGlobe = millis();
        globeFrame = (globeFrame + 1) % GLOBE_FRAMES;
        drawClockFace(pageDirty);
        pageDirty = false;
      }
    } else if (pageDirty) {
      drawPage(true);
      pageDirty = false;
    }
  }

#if ENABLE_BLE
  static unsigned long lastAncs = 0;
  if (bleLinked && millis() - lastAncs > 5000) {
    lastAncs = millis();
    bleHookAncs();
  }
#endif
}

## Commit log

2026-08-28 first batch of PCB files
    [.step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]
2026-08-30 add readme, drop CAD placeholder
2026-09-03 adding the CAD files
    [Assembly 2.step, Base CAD.step, Top CAD.step]
2026-09-03 Create blank folder to allow me to add teh cad folder
2026-09-04 respace key matrix to 19.05mm and reroute
    the 3x3 matrix was on 15.09mm centres. an mx switch is 15.6mm across the
    plate flange and a 1u dsa cap is 18.4mm, so neither the switches nor the
    caps could physically be fitted. moved to standard 19.05mm pitch.
    - switch centres x 77.70/96.75/115.80, y 52.00/71.05/90.10
    - one diode per switch, in the gap directly below it, instead of a column
    of nine at the board edge
    - H3 and H4 moved outward in x to clear the wider key block
    - U1 and J1 flipped to B.Cu per the blare guide, buzzer left on F.Cu
    - fully rerouted, 461 tracks and 14 vias, drc clean with nothing unrouted
    - fixes 17 co-located drill holes and 6 dangling tracks/vias in the old
    routing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
    [.step, board.step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]
2026-09-04 add zipped gerbers for the fab
    PCB/gerbers.zip holds the nine fab layers plus the drill file, flat, which
    is the shape jlcpcb's uploader expects. same content as PCB/gerber/, just
    packaged.
    readme points at it.
2026-09-04 move CAD into a real CAD/ directory
    replaces the 1-byte CAD blob, which was a placeholder github made when
    trying to create an empty folder, and was blocking git from indexing a
    real directory at that path.
    - CAD/Bottom.step, CAD/Top.step case parts
    - CAD/Top_Bottom_Assembly.step both case parts together
    - CAD/Full_Assembly.step case + pcb, buzzer, diodes, header
    drops the old root level Assembly 2.step, Base CAD.step and Top CAD.step,
    which were the pre relayout versions.
    [Assembly 2.step, Base CAD.step, Bottom.step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]
2026-09-04 finish the firmware, fix the matrix pin map
    the pin map was wrong. rows and columns had D8 and D10 swapped against the
    board, so row 3 and column 3 were crossed and the matrix could not have
    scanned. rows are D0 D10 D9, columns are D6 D7 D8, taken from the netlist.
    readme pin table had the same swap.
    new:
    - spinning globe on the clock face, the 24 frame animation off my hackpad
    - 4 alarms, each with its own days of the week, edited on the device
    - info pages for weather, hackatime, now playing and world clocks
    - one https request a minute to the relay, one json back for all four pages
    - pages auto rotate after 20s idle, or arrow through them
    ble media remote and ancs notifications are writ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
    [firmware.ino]
2026-09-04 make the ble path actually compile
    installed the esp32 core and the libraries and built the sketch for real,
    which turned up three things no amount of reading was going to catch.
    - the .ino preprocessor hoists its generated prototypes to the top of the
    file, so the nimble headers had to move up with the other includes. as
    written every ancs callback failed with "declared void"
    - HID_KEYBOARD is from the esp32 core BLE library, not nimble. replaced
    with the raw appearance value 0x03C1
    - NimBLEHIDDevice::startServices() is deprecated in nimble 2.x, the server
    starts them now
    measured, esp32 core 3.3.11, XIAO_ESP32C3:
    ENABLE_BLE 0 1155141 bytes 88% of the default partition
    ENA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
    [firmware.ino]
2026-09-09 add real images to the readme, drop the placeholders
    the five image links were all TODO-*.png placeholders pointing at files that
    never existed, so they rendered as broken images on github.
    generated from the actual project files:
    - images/pcb-3d.png raytraced board render, kicad-cli pcb render
    - images/schematic.png exported from the .kicad_sch
    - images/pcb-front.png f.cu + f.silkscreen + edge cuts
    - images/pcb-back.png b.cu + b.silkscreen + edge cuts, mirrored
    - images/case.png isometric of CAD/Full_Assembly.step
    also fills two gaps a reader would hit: the readme never described the case at
    all, and never said how to build or flash the thing. both have sections now.
2026-09-09 add mit licence, use the assembly render as the hero
    - LICENSE, mit
    - readme hero is images/full.webp, the onshape render of the whole thing
    - dropped the front and back copper views, one pcb image is enough
    - no TODO placeholders left in the readme
2026-09-09 Remove case and building instructions from README
    Removed sections about the case and building instructions from the README.
2026-09-10 widen the case to 79mm and add real display mounting
    the display is 73.15mm long and the clear span between the side walls was
    70.50mm, so it did not fit the case in any orientation. it also could not
    seat on anything: the window was 24.00 wide against a 21.08 display, so it
    would have dropped straight through.
    - base Extrude 1 depth 75.3 -> 79 mm, clear span is now 74.20
    - top plate outline 75.30 -> 79.00 so it still covers. its key cutout does
    not move, so the offsets are now 8.65 one side and 12.35 the other
    - display window 24.00 x 65.00 -> 18.40 x 63.00, sized to the 62.50 x 17.90
    glass. the pcb now overlaps the opening by 5.08 at each end and 1.34 down
    each side, so it has somet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
    [Bottom.step, Full_Assembly.step, Top.step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]
2026-09-10 add the display mounting render, swap the hero to png
    screw_holes.png goes right under the hero since it shows the two pilots the
    display bolts into. drops case.png, the wireframe was a duller copy of what
    the hero already shows.
2026-09-10 reorganise the readme
    folded the loose "pics" section into the sections the images belong to, and
    merged "why" and "how it works" into the intro and the board section. the
    images now sit next to the thing they show instead of in a gallery.
    - added a firmware section. there was none, and the minimal spiffs
    requirement was buried in a bullet list of features
    - case section updated for the 79mm width and the display screw mounting
    - repo table now lists the paths that actually exist. it claimed CAD/ held
    stls and an onshape link, neither of which are in here
    - bom lists the 2x m2 screws for the display, which the kit does not
    include, and notes the m3x16 and 4 inserts freed up by gluing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
2026-09-10 Clean up README by removing excess details
    Removed detailed sections about pins, case design, firmware, BOM, and repository structure from the README.
2026-09-11 mount the display on clamp bars with m3 inserts, add switches, caps and display to the cad
    - window moved 4.5mm up the slanted face so the bars clear the floor, display flipped
    so the glass is centred in the window with 0.25mm a side, flush with the outside
    - two printed clamp bars, each on two 6.6mm bosses with 4.6mm insert bores, edge-only
    clamp bands with a 1.5mm relief in the middle
    - pcb post holes to 4.6mm x 15 deep so the kit's inserts and m3x16 go there and the
    m3x8 go to the bars
    - buzzer hole in the top plate moved 3.8mm to sit over the buzzer
    - full assembly now carries mx switches, dsa caps, the display and both bars
    - new renders from onshape, readme caption updated
    [Bottom.step, Display_Clamp_Bar.step, Full_Assembly.step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]
2026-09-12 raise the pcb so the keycaps sit above the top plate, align the buzzer and usb cutout
    - pcb up 13.9mm: new 31.3mm posts placed exactly on the pcb's four holes, 4.6mm x 5
    insert bores with 3.2mm clearance below for the kit's m3x16; the old posts, their
    hole feature and chamfer are suppressed. front-left post narrowed so the display's
    jumper housings clear it
    - keycap skirts now sit 0.5mm above the plate, buzzer pokes 0.8mm through its hole,
    key cutout re-centred on the caps
    - display mounting reworked to fit under the raised pcb: lip along the top edge on
    the wall, one 60mm clamp rail on two bosses along the bottom edge
    - usb cutout moved up with the pcb and centred on the xiao port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
    [Bottom.step, Display_Clamp_Bar.step, Display_Clamp_Rail.step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]
2026-09-12 screw the display rail from the front
    - rail now sits straight on the wall (bosses gone) with two 4.6mm insert bores on its
    wall face, and 3.2mm clearance holes through the front wall at the same spots
    - two m3x8 button heads come in through the front into the rail
    - screws modelled in the full assembly, renders and readme caption updated
    [Bottom.step, Display_Clamp_Rail.step, Full_Assembly.step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]
2026-09-18 screw the top plate down on its own bosses, put the keys on the real footprints
    - four wall bosses just above the pcb with 4.6 x 5 insert bores and 3.2 through holes,
    four 3.2 clearance holes in the plate, m3x8 screws. separate from the pcb posts
    - switches, keycaps and the plate cutout were 2.54 x 5.08 off the routed board, moved
    onto the real footprint grid. one diode body was floating, put back
    - pcb posts checked against the kicad holes, they line up
    - socketed xiao modelled under the board so the usb slot can be seen lining up with
    the port, which sits 13mm below the pcb
    - dropped a stray 0.5mm pocket on the back of the plate
    - step files, renders and readme updated
    [Bottom.step, Full_Assembly.step, Top.step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]
2026-09-26 Merge top-plate and PCB screw hardware into one fastener per corner
    The top-plate bosses now land on the PCB's own mounting holes and
    fuse into the PCB posts, so a single M3x16 screw per corner secures
    both the plate and the board through the board's existing heatset
    insert instead of running two separate screw/insert systems.
2026-09-26 Remove stale gerber export
    The PCB layout has moved on since these gerbers/drill files and the
    zip were generated; drop them until a fresh export matches the
    current board.
    [kicad_schematic-B_Cu.gbr, kicad_schematic-B_Mask.gbr, kicad_schematic-B_Paste.gbr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]
2026-09-26 Re-export CAD from Onshape: buzzer/keycap fixes, fastener merge
    Refreshes the STEP exports for all existing parts and assemblies to
    match the current Onshape state (buzzer hole realignment, DSA keycap
    fix, top-plate/PCB fastener merge). Also adds STEP exports for the
    DSA_keycap and XIAO_ESP32C3_socketed part studios, which previously
    had no export tracked in the repo.
    [Bottom.step, DSA_keycap.step, Display_Clamp_Rail.step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]
2026-09-26 Regenerate gerbers from current PCB layout
    Re-exported via kicad-cli from kicad_schematic.kicad_pcb (same layer
    set and job-file settings as the previous export) so PCB/gerber and
    gerbers.zip match the board as currently routed.
    [kicad_schematic-B_Cu.gbr, kicad_schematic-B_Mask.gbr, kicad_schematic-B_Paste.gbr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]
2026-09-26 Mount display via its own screw holes instead of the clamp bar
    Plug the two old clamp-bar M3 screw holes in the case wall and cut
    new 2.5mm holes at the display's own mounting hole centers (16.26mm
    apart), so the display screws directly to the wall. Full Assembly
    still references the now-unused clamp rail and its screws; that
    cleanup is pending in the Onshape document.
    [Bottom.step]
2026-09-26 updated cad files
    [Bottom.step, DSA_keycap.step, Display_Clamp_Rail.step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]
2026-10-23 adding BOM as per reviewer
2026-10-23 Correct filename case for BOM.csv in README
2026-10-23 Add KiCad PCB layout image to README
2026-10-27 Move assembly CAD files into CAD/do_not_print
